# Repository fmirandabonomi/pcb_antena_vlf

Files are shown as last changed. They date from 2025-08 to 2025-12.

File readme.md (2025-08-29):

<!-- markdownlint-disable-file MD013 -->
# Antena VLF, Laboratorio de Telecomunicaciones FACET UNT

En este repositorio se encuentran los diseños de los acondicionadores de señales y módulo de adquisición de la antena de VLF desarrollada en el Laboratorio de Telecomunicaciones, FACET UNT en el periodo 2024-2025

La antena de VLF consiste en un par de antenas de lazo dispuestas en cuadratura. Cada antena de lazo es conectada a un acondicionador de señal que cumple las funciones de convertidor corriente/tensión y filtro. La salida de los acondicionadores es adquirida por un módulo de adquisición y transmitida via Ethernet hasta una computadora para su proceso y almacenamiento.

## Contenido

- **/adquisicion** : Directorio conteniendo el proyecto de KiCad del módulo de adquisición.
- **/acondicionador** : Directorio conteniendo el proyecto de KiCad del módulo acondicionador de señal.

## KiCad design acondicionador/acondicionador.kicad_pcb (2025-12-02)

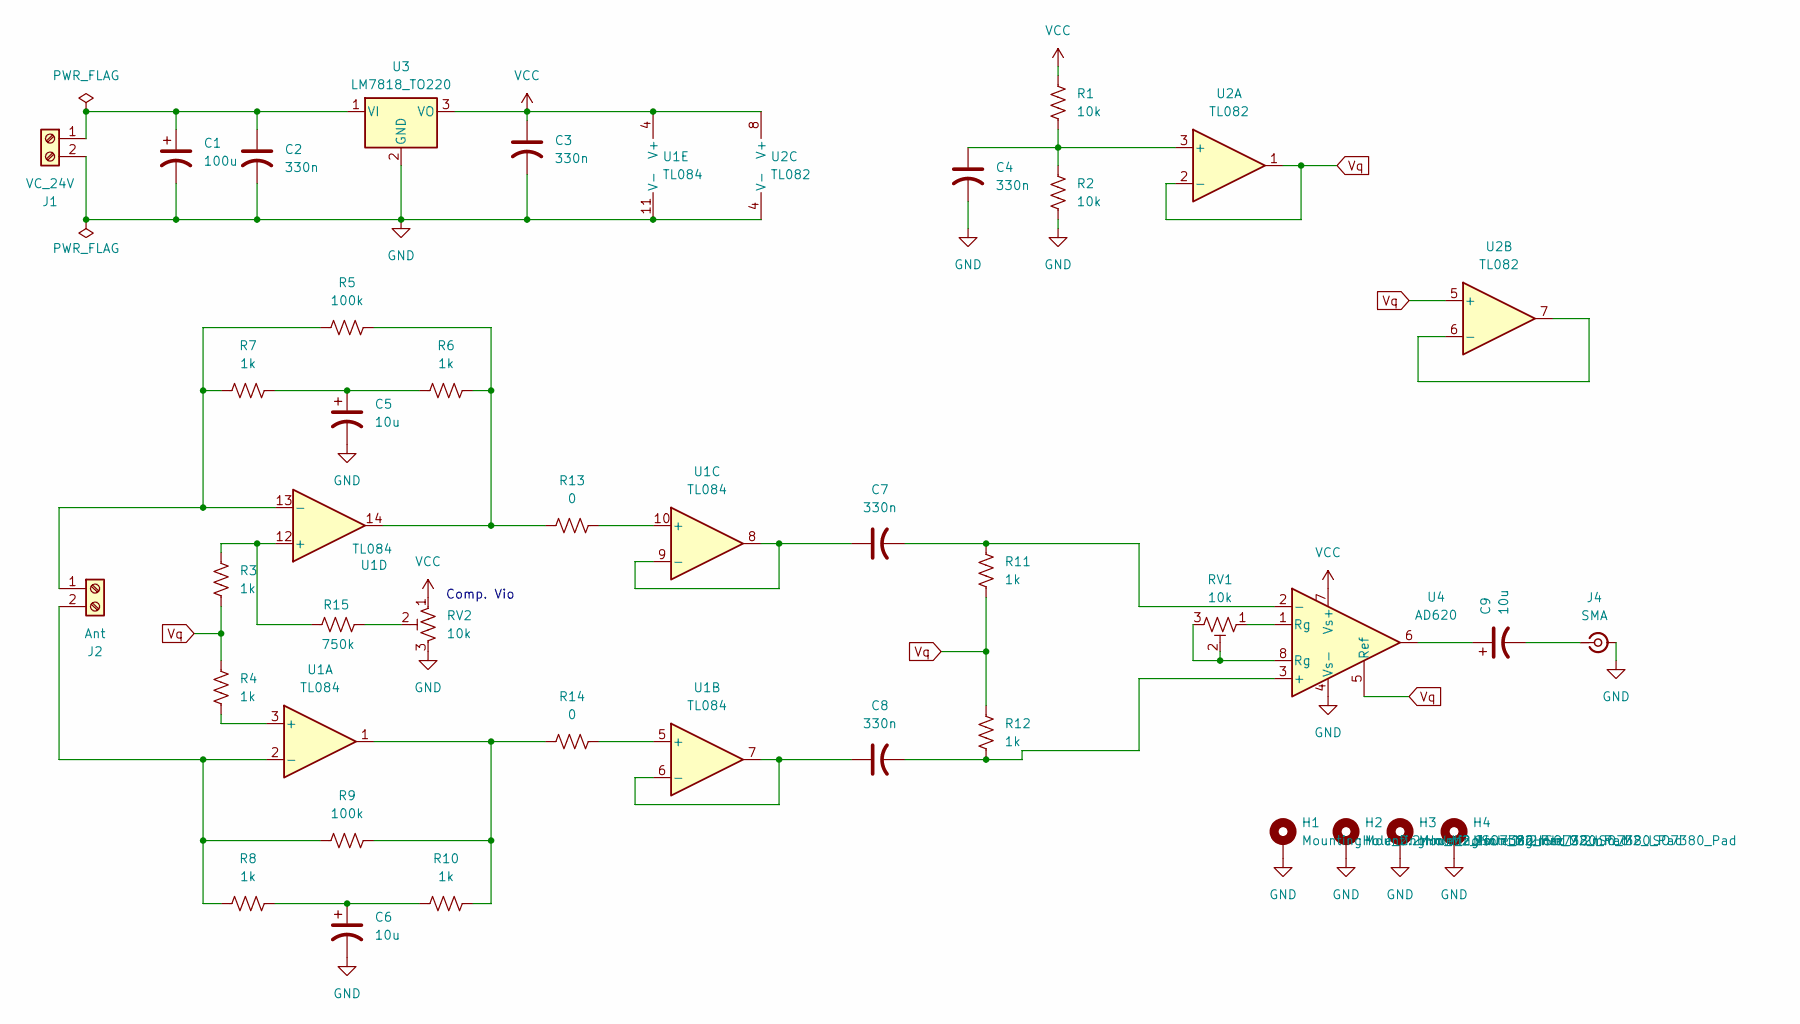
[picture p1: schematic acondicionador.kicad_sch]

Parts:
C1: 100u; CP_Radial_D10.0mm_P5.00mm-pad2mm2
C2, C3, C4, C7, C8: 330n; C_Disc_D5.1mm_W3.2mm_P5.00mm-pad2mm
C5, C6, C9: 10u; CP_Radial_D10.0mm_P5.00mm-pad2mm2
H1, H2, H3, H4: MountingHole_2.2mm_M2_ISO7380_Pad
J1: VC_24V; TerminalBlock_MetzConnect_Type011_RT05502HBLC_1x02_P5.00mm_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
J2: Ant; TerminalBlock_MetzConnect_Type011_RT05502HBLC_1x02_P5.00mm_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
J4: SMA; SMA_Samtec_SMA-J-P-H-ST-EM1_EdgeMount
R1, R2: 10k; R_Axial_DIN0207_L6.3mm_D2.5mm_P10.16mm_Horizontal-pad2mm
R3, R4: 1k; R_Axial_DIN0207_L6.3mm_D2.5mm_P15.24mm_Horizontal-pad2mm
R5, R9: 100k; R_Axial_DIN0207_L6.3mm_D2.5mm_P10.16mm_Horizontal-pad2mm
R6, R7, R8, R10, R11, R12: 1k; R_Axial_DIN0207_L6.3mm_D2.5mm_P10.16mm_Horizontal-pad2mm
R13, R14: 0; R_Axial_DIN0207_L6.3mm_D2.5mm_P10.16mm_Horizontal-pad2mm
R15: 750k; R_Axial_DIN0207_L6.3mm_D2.5mm_P10.16mm_Horizontal-pad2mm
RV1, RV2: 10k; Potentiometer_Bourns_3296W_Vertical-pad2mm
U1: TL084; DIP-14_W7.62mm_LongPads-2mm
U2: TL082; DIP-8_W7.62mm_LongPads-pad2mm
U3: LM7818_TO220; TO-220-3_Vertical-pad2mm
U4: AD620; DIP-8_W7.62mm_LongPads-pad2mm

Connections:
GND: C1.2, C2.2, C3.2, C4.2, C5.2, C6.2, H1.1, H2.1, H3.1, H4.1, J1.2, J4.2 (Ext), R2.2, RV2.3, U1.11 (V-), U2.4 (V-), U3.2 (GND), U4.4 (Vs-)
unnamed: C5.1, R6.1, R7.2
unnamed: C6.1, R8.2, R10.1
unnamed: C9.1, U4.6
unnamed: C1.1, C2.1, J1.1, U3.1 (VI)
unnamed: J2.1, R5.1, R7.1, U1.13 (-)
unnamed: J2.2, R8.1, R9.1, U1.2 (-)
unnamed: C9.2, J4.1 (In)
unnamed: R9.2, R10.2, R14.1, U1.1
unnamed: R5.2, R6.2, R13.1, U1.14
unnamed: R15.2, RV2.2
unnamed: RV1.1, U4.1 (Rg)
unnamed: RV1.2, RV1.3, U4.8 (Rg)
unnamed: R4.2, U1.3 (+)
unnamed: R14.2, U1.5 (+)
unnamed: C8.1, U1.6 (-), U1.7
unnamed: R13.2, U1.10 (+)
unnamed: C7.1, U1.8, U1.9 (-)
unnamed: R3.1, R15.1, U1.12 (+)
unnamed: C4.1, R1.2, R2.1, U2.3 (+)
unnamed: U2.6 (-), U2.7
unnamed: C8.2, R12.2, U4.3 (+)
unnamed: C7.2, R11.1, U4.2 (-)
VCC: C3.1, R1.1, RV2.1, U1.4 (V+), U2.8 (V+), U3.3 (VO), U4.7 (Vs+)
Vq: R3.2, R4.1, R11.2, R12.1, U2.1, U2.2 (-), U2.5 (+), U4.5 (Ref)

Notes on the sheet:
Comp. Vio

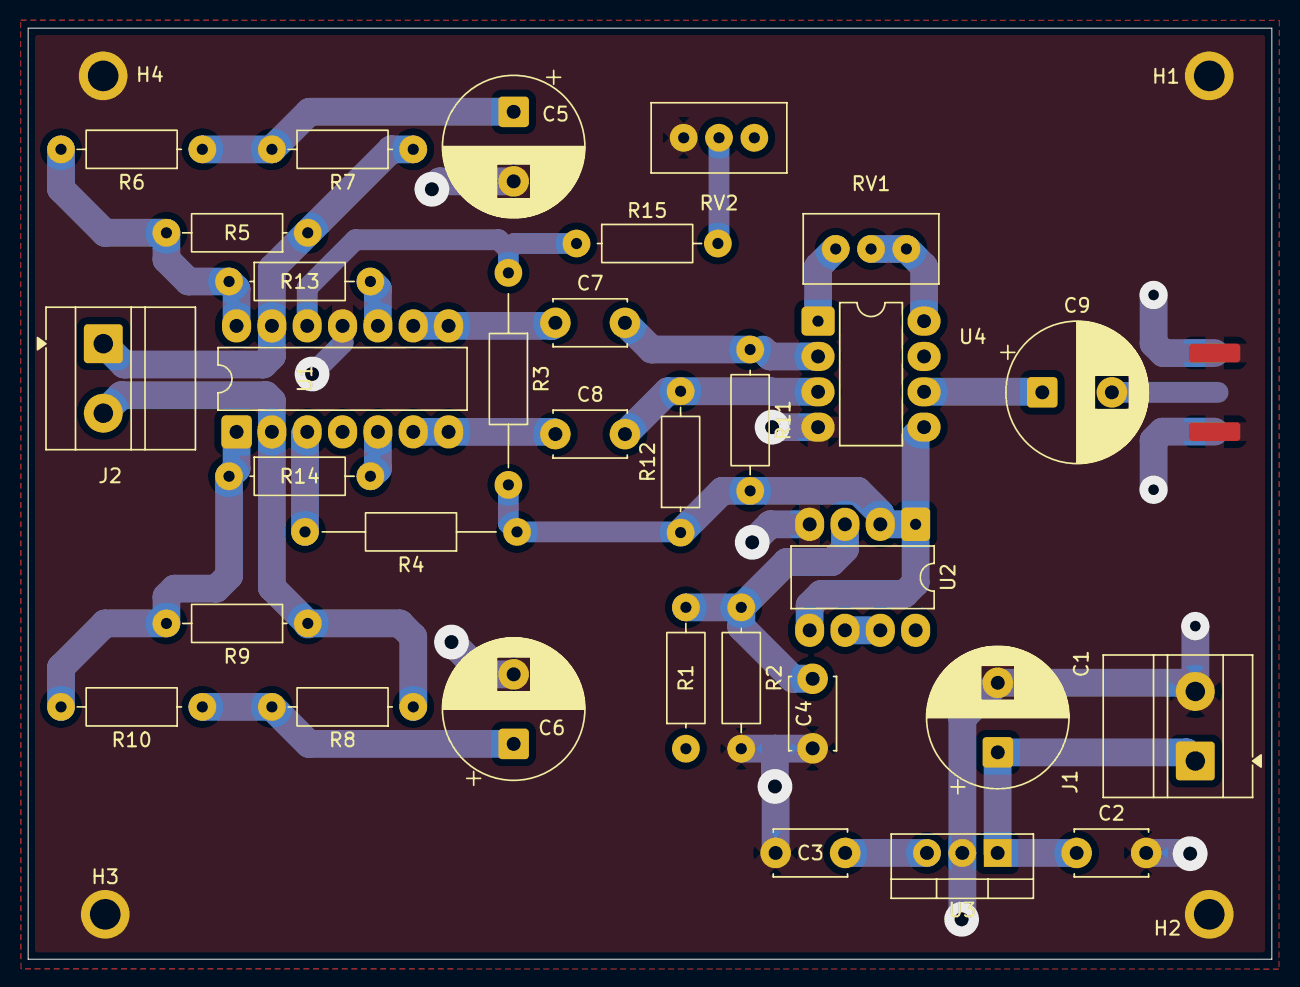
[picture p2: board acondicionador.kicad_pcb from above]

Board: 2 copper layers, 89.4 x 66.9 mm, 37 parts (1 on the bottom side), 25 nets.

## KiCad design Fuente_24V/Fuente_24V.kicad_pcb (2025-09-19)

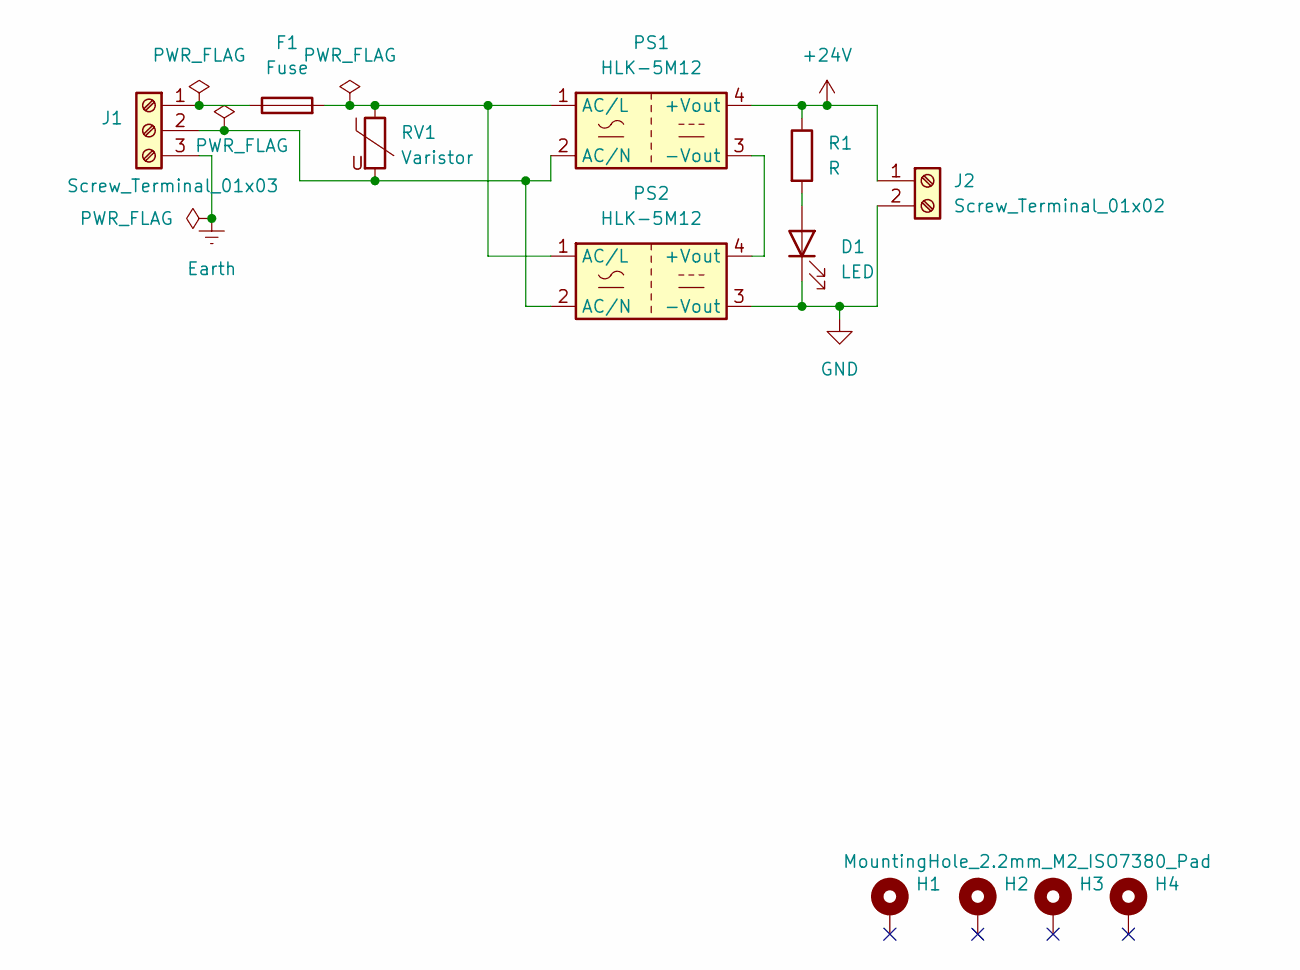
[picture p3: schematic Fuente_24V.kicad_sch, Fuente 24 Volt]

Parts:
D1: LED; LED_D3.0mm
F1: Fuse; Fuseholder_Cylinder-5x20mm_Schurter_0031_8201_Horizontal_Op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
H1, H2, H3, H4: MountingHole_2.2mm_M2_ISO7380_Pad
J1: Screw_Terminal_01x03; TerminalBlock_MaiXu_MX126-5.0-03P_1x03_P5.00mm
J2: Screw_Terminal_01x02; TerminalBlock_MaiXu_MX126-5.0-02P_1x02_P5.00mm
PS1, PS2: HLK-5M12; Converter_ACDC_Hi-Link_HLK-5Mxx
R1: R; R_Axial_DIN0207_L6.3mm_D2.5mm_P10.16mm_Horizontal
RV1: Varistor; RV_Disc_D12mm_W4mm_P7.5mm

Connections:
+24V: J2.1, PS1.4 (+Vout), R1.1
Earth: J1.3
GND: D1.1 (K), J2.2, PS2.3 (-Vout)
unnamed: D1.2 (A), R1.2
unnamed: F1.1, J1.1
unnamed: J1.2, PS1.2 (AC/N), PS2.2 (AC/N), RV1.2
unnamed: PS1.3 (-Vout), PS2.4 (+Vout)
unnamed: F1.2, PS1.1 (AC/L), PS2.1 (AC/L), RV1.1

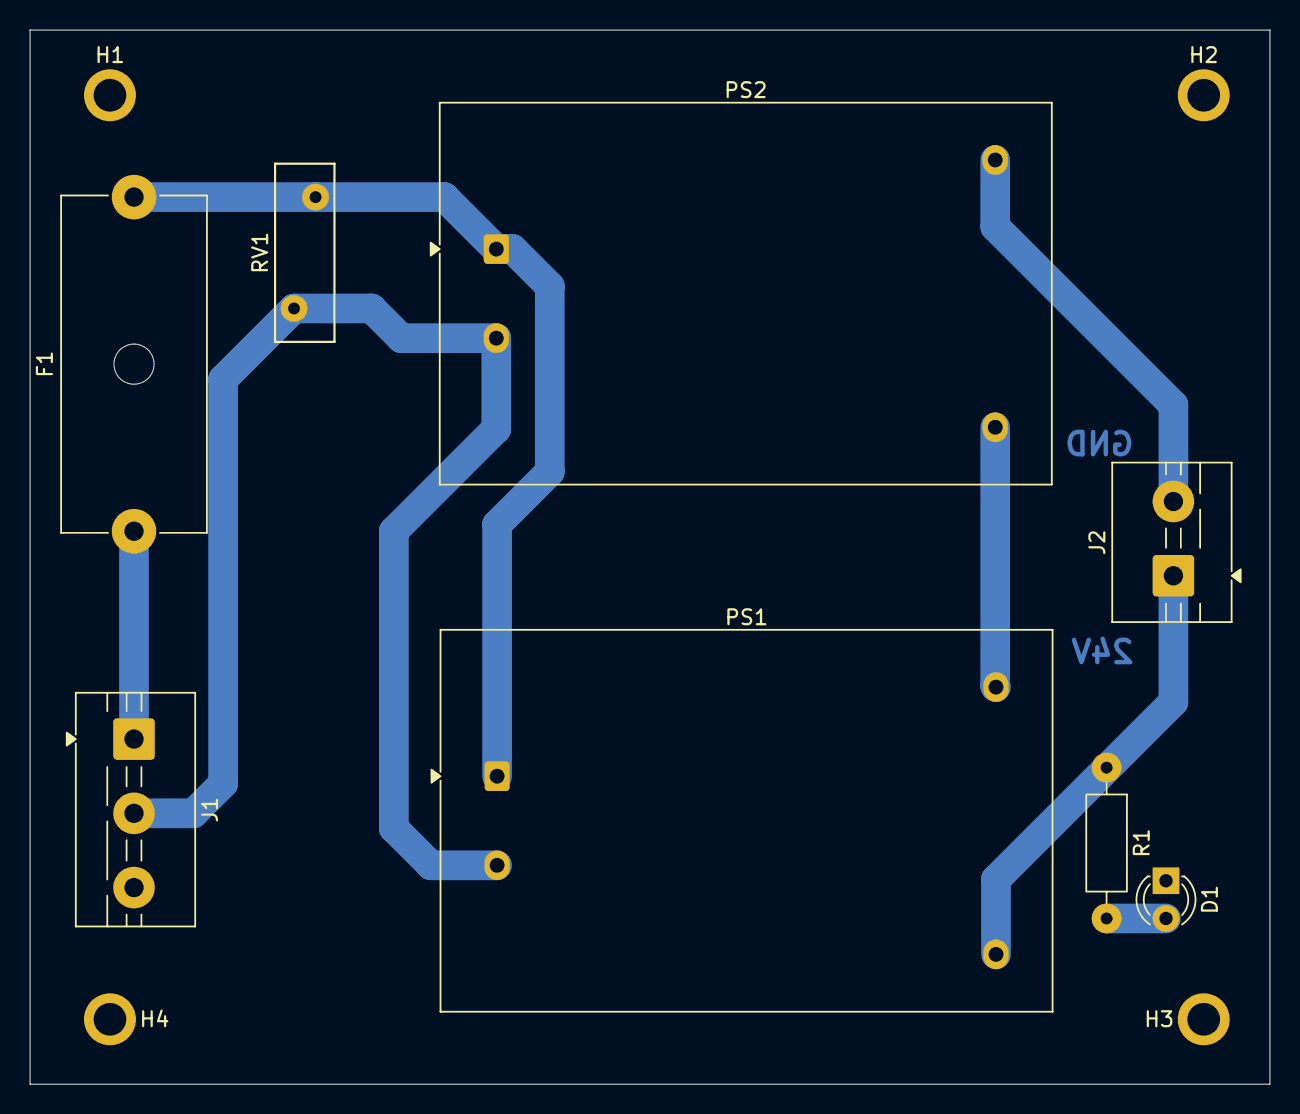
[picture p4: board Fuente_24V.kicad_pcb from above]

Board: 2 copper layers, 83.5 x 71.0 mm, 12 parts (0 on the bottom side), 7 nets.

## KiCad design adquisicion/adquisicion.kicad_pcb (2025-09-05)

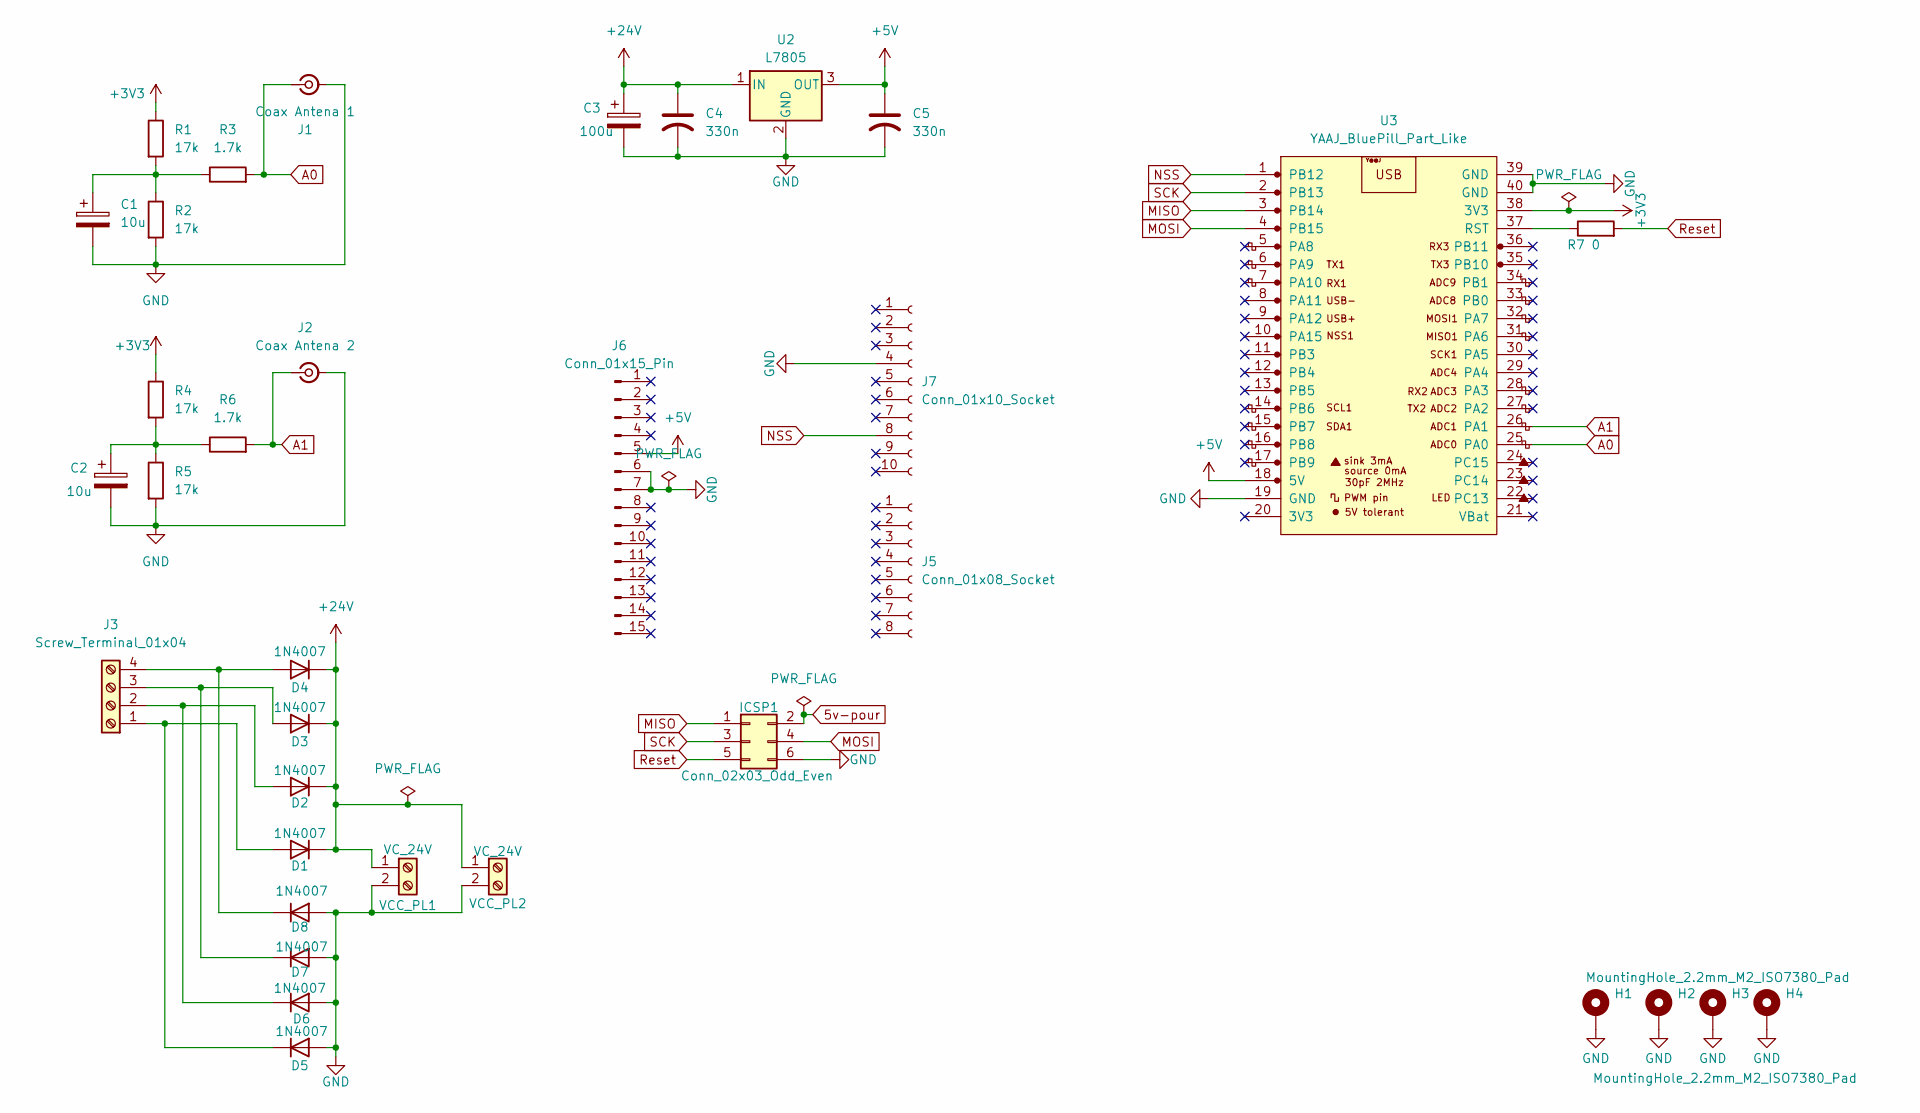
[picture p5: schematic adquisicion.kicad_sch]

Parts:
C1, C2: 10u; CP_Radial_D10.0mm_P5.00mm
C3: 100u; CP_Radial_D10.0mm_P5.00mm
C4, C5: 330n; C_Disc_D5.1mm_W3.2mm_P5.00mm-pad2mm
D1, D2, D3, D4, D5, D6, D7, D8: 1N4007; D_DO-41_SOD81_P10.16mm_Horizontal
H1, H2, H3, H4: MountingHole_2.2mm_M2_ISO7380_Pad
ICSP1: Conn_02x03_Odd_Even; PinHeader_2x03_P2.54mm_Vertical
J1: Coax Antena 1; SMA_Samtec_SMA-J-P-H-ST-EM1_EdgeMount
J2: Coax Antena 2; SMA_Samtec_SMA-J-P-H-ST-EM1_EdgeMount
J3: Screw_Terminal_01x04; TerminalBlock_MetzConnect_Type011_RT05504HBLC_1x04_P5.00mm_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
J5: Conn_01x08_Socket; PinHeader_1x08_P2.54mm_Vertical
J6: Conn_01x15_Pin; PinHeader_1x15_P2.54mm_Vertical
J7: Conn_01x10_Socket; PinHeader_1x10_P2.54mm_Vertical
R1, R2, R4, R5: 17k; R_Axial_DIN0207_L6.3mm_D2.5mm_P10.16mm_Horizontal-pad2mm
R3, R6: 1.7k; R_Axial_DIN0207_L6.3mm_D2.5mm_P10.16mm_Horizontal-pad2mm
R7: 0; R_Axial_DIN0207_L6.3mm_D2.5mm_P15.24mm_Horizontal-pad2mm
U2: L7805; TO-220-3_Vertical
U3: YAAJ_BluePill_Part_Like; YAAJ_BluePill_2
VCC_PL1, VCC_PL2: VC_24V; TerminalBlock_MetzConnect_Type011_RT05502HBLC_1x02_P5.00mm_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

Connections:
5v-pour: ICSP1.2
+3V3: R1.1, R4.1, U3.38 (3V3)
+5V: C5.1, J6.5, U2.3 (OUT), U3.18 (5V)
+24V: C3.1, C4.1, D1.1 (K), D2.1 (K), D3.1 (K), D4.1 (K), U2.1 (IN), VCC_PL1.1, VCC_PL2.1
A0: J1.1 (In), R3.2, U3.25 (PA0)
A1: J2.1 (In), R6.2, U3.26 (PA1)
GND: C1.2, C2.2, C3.2, C4.2, C5.2, D5.2 (A), D6.2 (A), D7.2 (A), D8.2 (A), H1.1, H2.1, H3.1, H4.1, ICSP1.6, J1.2 (Ext), J2.2 (Ext), J6.6, J6.7, J7.4, R2.2, R5.2, U2.2 (GND), U3.19 (GND), U3.39 (GND), U3.40 (GND), VCC_PL1.2, VCC_PL2.2
MISO: ICSP1.1, U3.3 (PB14)
MOSI: ICSP1.4, U3.4 (PB15)
NSS: J7.8, U3.1 (PB12)
unnamed: C1.1, R1.2, R2.1, R3.1
unnamed: C2.1, R4.2, R5.1, R6.1
unnamed: D1.2 (A), D5.1 (K), J3.1
unnamed: D2.2 (A), D6.1 (K), J3.2
unnamed: D3.2 (A), D7.1 (K), J3.3
unnamed: D4.2 (A), D8.1 (K), J3.4
unnamed: R7.1, U3.37 (RST)
Reset: ICSP1.5, R7.2
SCK: ICSP1.3, U3.2 (PB13)

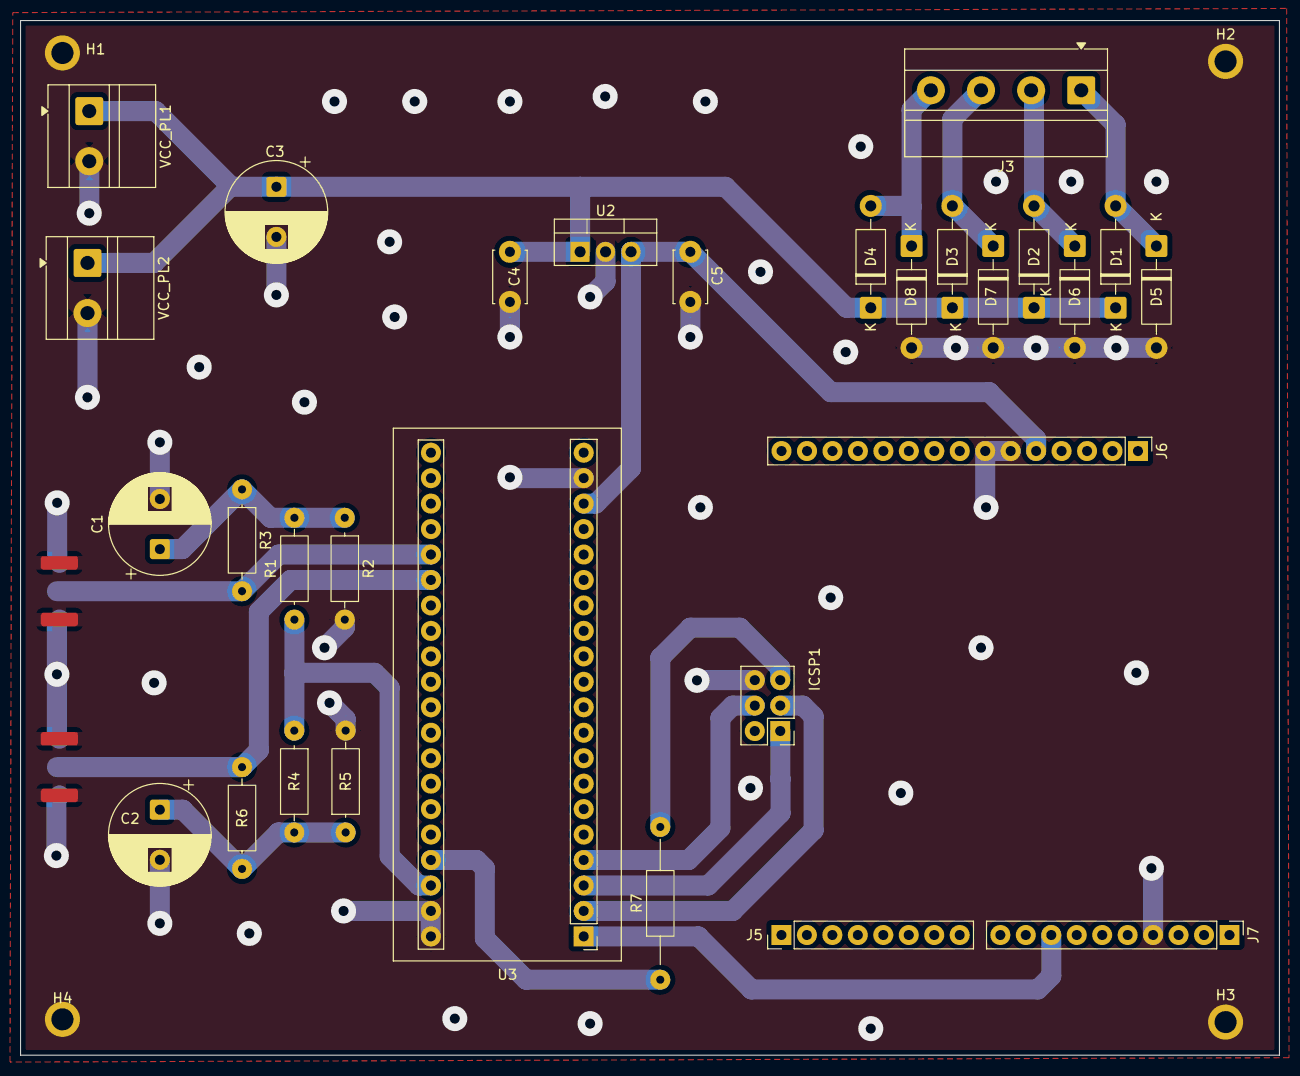
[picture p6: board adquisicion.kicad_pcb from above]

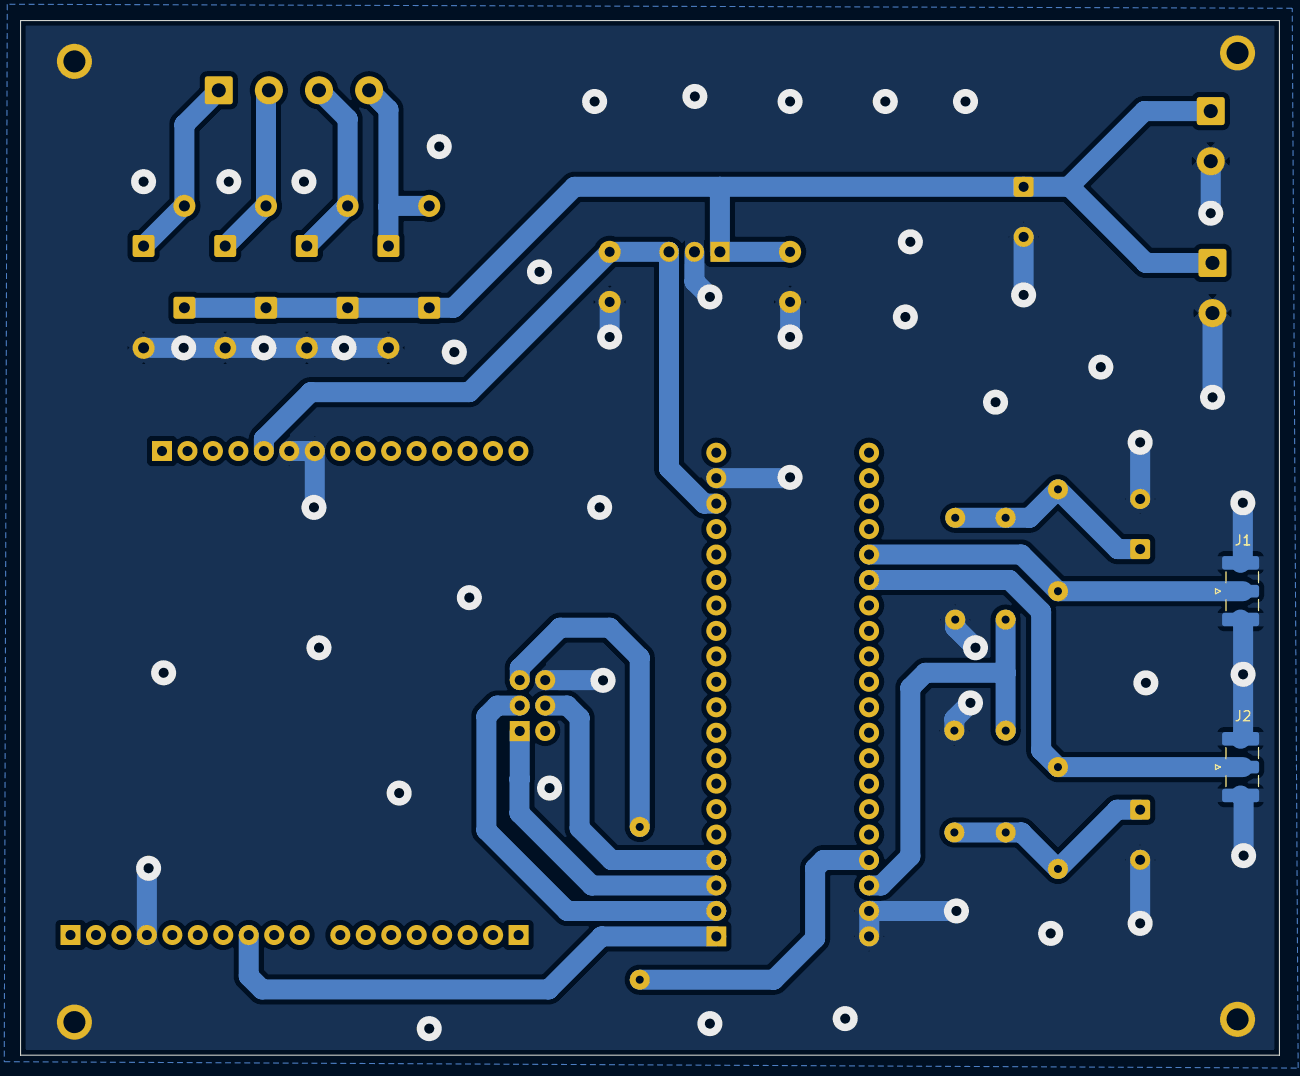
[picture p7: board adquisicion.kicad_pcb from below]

Board: 2 copper layers, 125.6 x 103.2 mm, 35 parts (2 on the bottom side), 18 nets.

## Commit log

2025-08-19 Versión inicial
    [pcb_antena.kicad_pcb, pcb_antena.kicad_sch]
2025-08-20 Pasaje de componentes y netlist a pcb
    [pcb_antena.kicad_pcb, pcb_antena.kicad_sch]
2025-08-21 Versión lista para imprimir
    [pcb_antena.kicad_pcb, pcb_antena.kicad_sch]
2025-08-28 Se agrego la otra placa en carpeta una nueva carpeta. Para revisión
    [Segunda_Parte.kicad_pcb, Segunda_Parte.kicad_sch, pcb_antena.kicad_pcb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]
2025-08-29 Organización del repositorio
    [Segunda_Parte.kicad_pcb, Segunda_Parte.kicad_sch, pcb_antena.kicad_pcb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]
2025-08-29 Cambio de nombres de proyectos kicad
    [acondicionador.kicad_pcb, acondicionador.kicad_sch, adquisicion.kicad_pcb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]
2025-08-29 Mejoras layout, corrección ERC y DRC
    [adquisicion.kicad_pcb, adquisicion.kicad_sch]
2025-09-05 Modificación posición C5 C6 en placa Acondicionador y cambio de huella sma (verificar), cambio de huella sma en placa Adquisición (verificar)
    [acondicionador.kicad_pcb, acondicionador.kicad_sch, adquisicion.kicad_pcb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]
2025-09-10 se modifica la disposición de los elementos
    [acondicionador.kicad_pcb]
2025-09-16 Se genera un nuevo proyecto para fuente
    [Fuente_24V.kicad_pcb, Fuente_24V.kicad_sch]
2025-09-17 Se agrega el gitIgnore para el proyecto
2025-09-17 Se agrega el esquemático y pcb de Fuente
    [Fuente_24V.kicad_pcb, Fuente_24V.kicad_sch]
2025-09-19 Se modifica el gitignore para ignorar una carpeta
2025-09-19 se agrega led indicador de fuente al esquema
    [Fuente_24V.kicad_pcb, Fuente_24V.kicad_sch]
2025-12-02 Compensación Voi acondicionador
    [acondicionador.kicad_pcb, acondicionador.kicad_sch]
